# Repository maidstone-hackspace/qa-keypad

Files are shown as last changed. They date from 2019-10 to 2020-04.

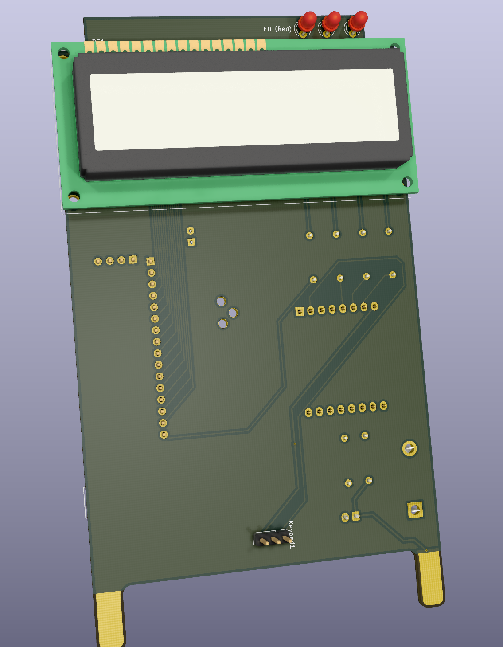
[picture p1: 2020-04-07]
PCB/Keypad_Front.png

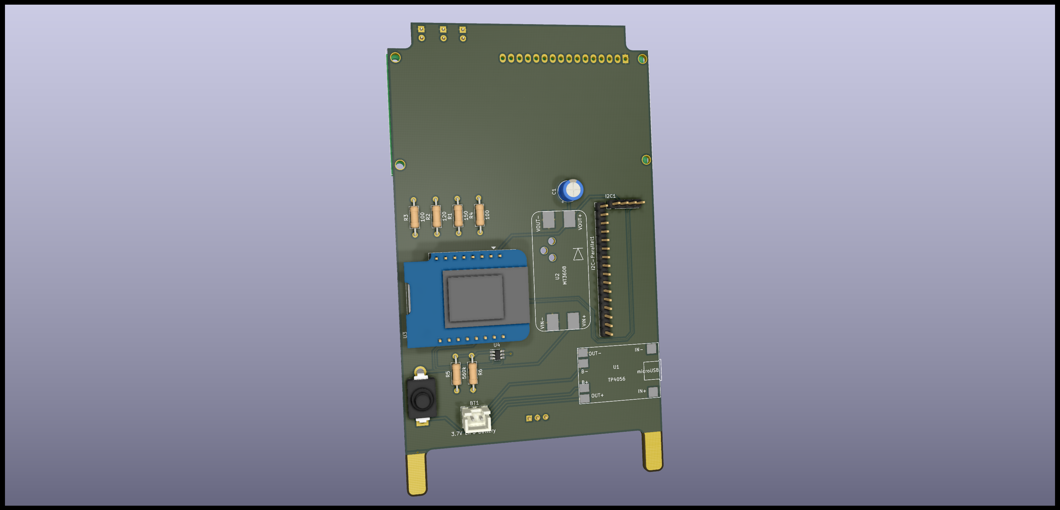
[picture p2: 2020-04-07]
PCB/Keypad_Rear.png

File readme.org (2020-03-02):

#+TITLE: Wemos QA keypad

* Device install

To setup a new device you can use the arduino software, you will need a plugin to upload the files in the =data= folder to your wemos device.

** Deploy requirements
https://github.com/esp8266/Arduino.git
https://github.com/esp8266/arduino-esp8266fs-plugin/releases/tag/0.4.0

** Build Requirements
You will also need various 3rd party libaries.
keypad.h 3.1.1 by Mark Stanley, Alexander Brevig https://wiring.uniandes.edu.co/source/trunk/wiring/

LiquidCrystal I2C by frank de Bradander https://github.com/johnrickman/LiquidCrystal_I2C

ESPAsyncWebServer https://github.com/me-no-dev/ESPAsyncWebServer/archive/master.zip

ESPAsyncTCP https://github.com/me-no-dev/ESPAsyncTCP

Extract and copy to arduino libries folder

* Device Setup

When switching on the device for the first time it will launch in access point mode to allow you to setup the device, connect to =weeeecfg= from a phone and enter password =weeeecfg= to setup the device. If the device can not connect to a local network it will relaunch the setup interface.

subsequent usage of the device will reuse the same settings as long as the device can connect.

The interfacing is using a simple web interface generated from this repository.

https://gitlab.com/olymk2/weecfg

#+RESULTS:
: None

* API example
** Keypad startup endpoint
#+BEGIN_SRC http :pretty :exports both
POST http://ng.snapwire-portal.co.uk/api/Startup
Content-Type: application/json

{"ControllerId": "DID1"}
#+END_SRC

#+RESULTS:
: {
:   "ControllerId": "DID1",
:   "AssignedName": "Bob"
: }

** Poll to determine when ready for next answer
#+BEGIN_SRC http :pretty :exports both
POST http://ng.snapwire-portal.co.uk/api/Poll
Content-Type: application/json

{}
#+END_SRC

#+RESULTS:
: {
:   "Timestamp": 132149528062145583,
:   "ReadyToAcceptAnswers": true
: }

** Example sending answer to api.
#+BEGIN_SRC http :pretty :exports both
POST http://ng.snapwire-portal.co.uk/api/SubmitAnswer
Content-Type: application/json

{"ControllerId": "sample string 1", "Answer": "A"}
#+END_SRC

#+RESULTS:
: {
:   "ConfirmReceived": true
: }

http://ng.snapwire-portal.co.uk/api/SubmitAnswer

* Later
** TODO gzip the html

The wemos is by no means fast so gzip so there is less data to send.
** TODO http error message on api failure.

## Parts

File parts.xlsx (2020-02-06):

WeMos D1 Mini | £1.58 | £31.65 | https://www.aliexpress.com/item/4000375278135.html
TP4056 | £0.24 | £4.77 | https://www.aliexpress.com/item/32802142444.html
MT3608 | £0.33 | £6.54 | https://www.aliexpress.com/item/4000207182126.html
18650 Li-ion cell (tabbed) | £0.00 |  | Paul?
16x2 LCD Character display | £1.43 | £28.67 | https://www.aliexpress.com/item/33007929472.html?spm=a2g0o.cart.0.0.64ca3c00Um8uOu&mp=1
I2C to Parallel Adaptor | £0.00 |  | included above
Mini Latching On/Off Switch | £0.00 |  | Paul?
MCP3421 (SOT23-6) | £1.03 | £20.67 | https://www.aliexpress.com/item/32881169619.html?spm=a2g0o.cart.0.0.61463c00gVNrOm&mp=1
1x16 Male pin header | £0.03 | £0.59 | https://www.aliexpress.com/item/32623553746.html
1x4 Male pin header | £0.00 |  | included above
1x3 Male pin header | £0.00 |  | included above
Analog output Keypad | £0.00 |  | Already purchased?
100 Ohm resistor | £0.02 | £0.40 | https://www.aliexpress.com/item/32952657927.html
500k Ohm resistor | £0.02 | £0.40
560k Ohm resistor | £0.02 | £0.40
PCB | £1.08 | £21.67 | https://jlcpcb.com

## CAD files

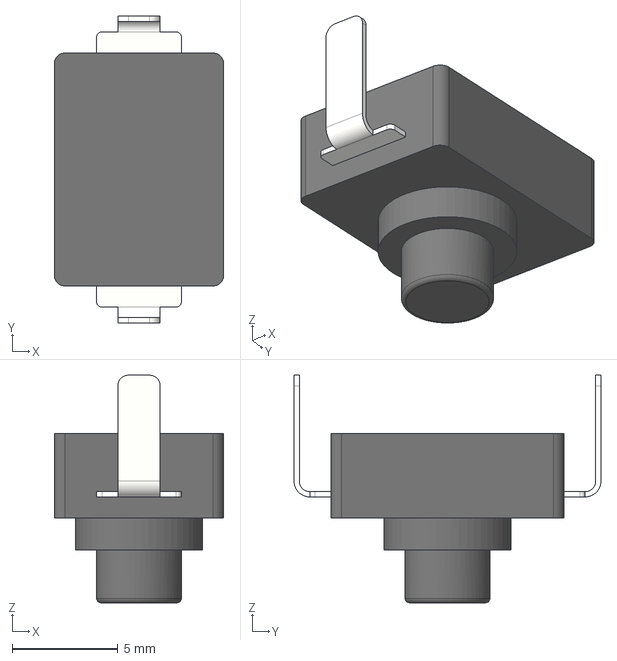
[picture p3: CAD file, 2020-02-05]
PCB/KiCad/Power Switch.step
8.00 x 14.5 x 10.8 mm

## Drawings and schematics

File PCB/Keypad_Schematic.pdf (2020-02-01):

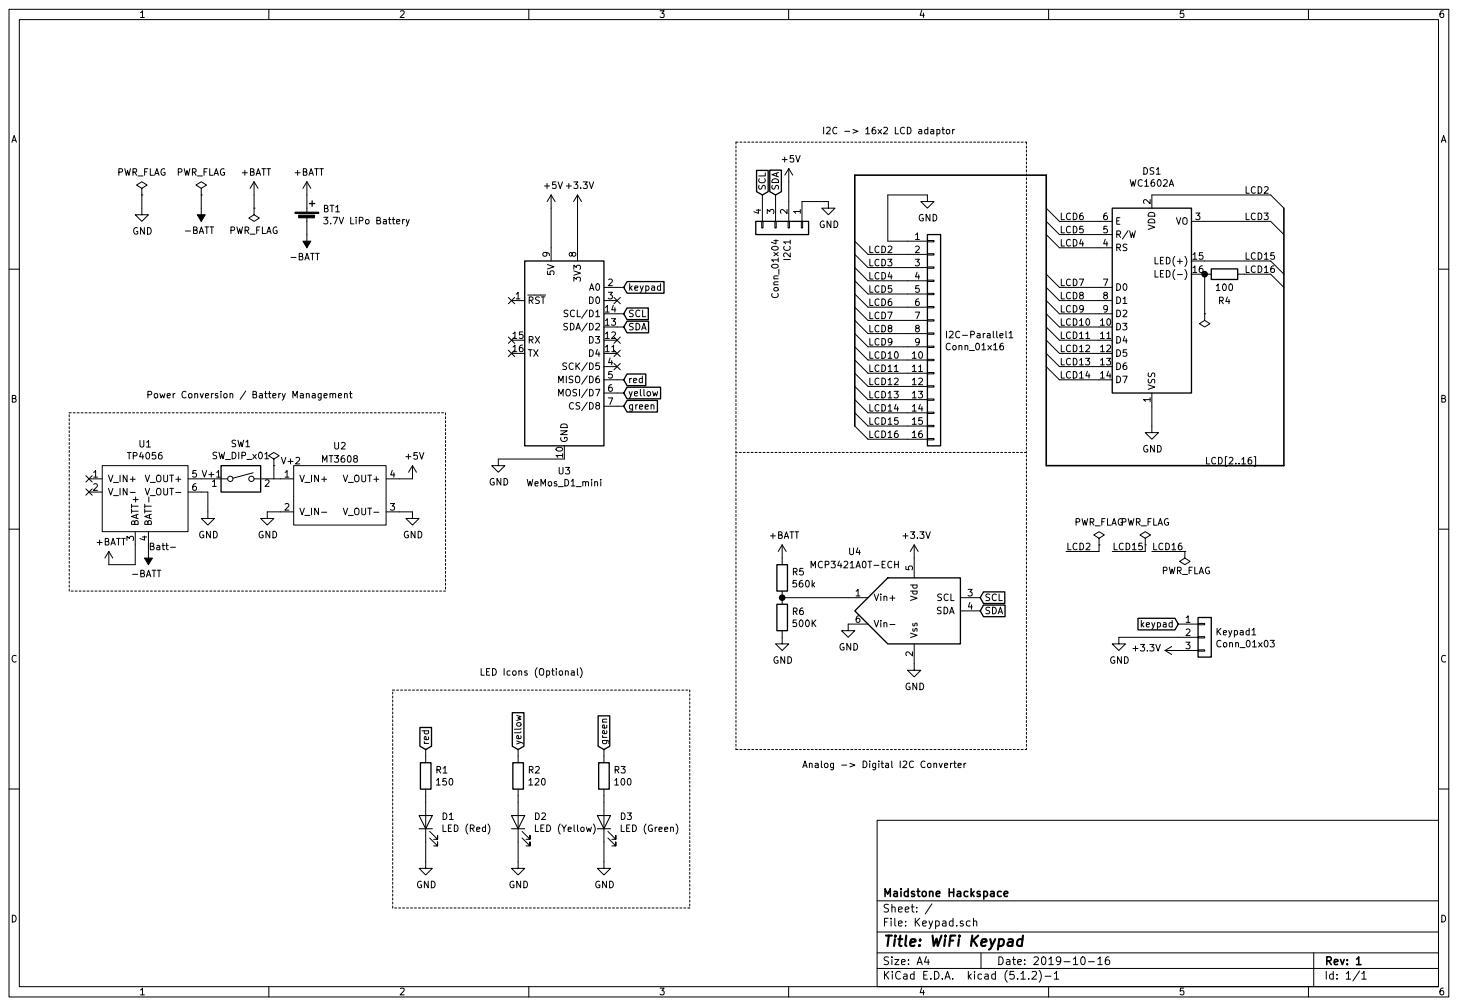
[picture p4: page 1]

File: Keypad.sch Sheet: / Maidstone Hackspace

Id: 1/1 Title: WiFi Keypad

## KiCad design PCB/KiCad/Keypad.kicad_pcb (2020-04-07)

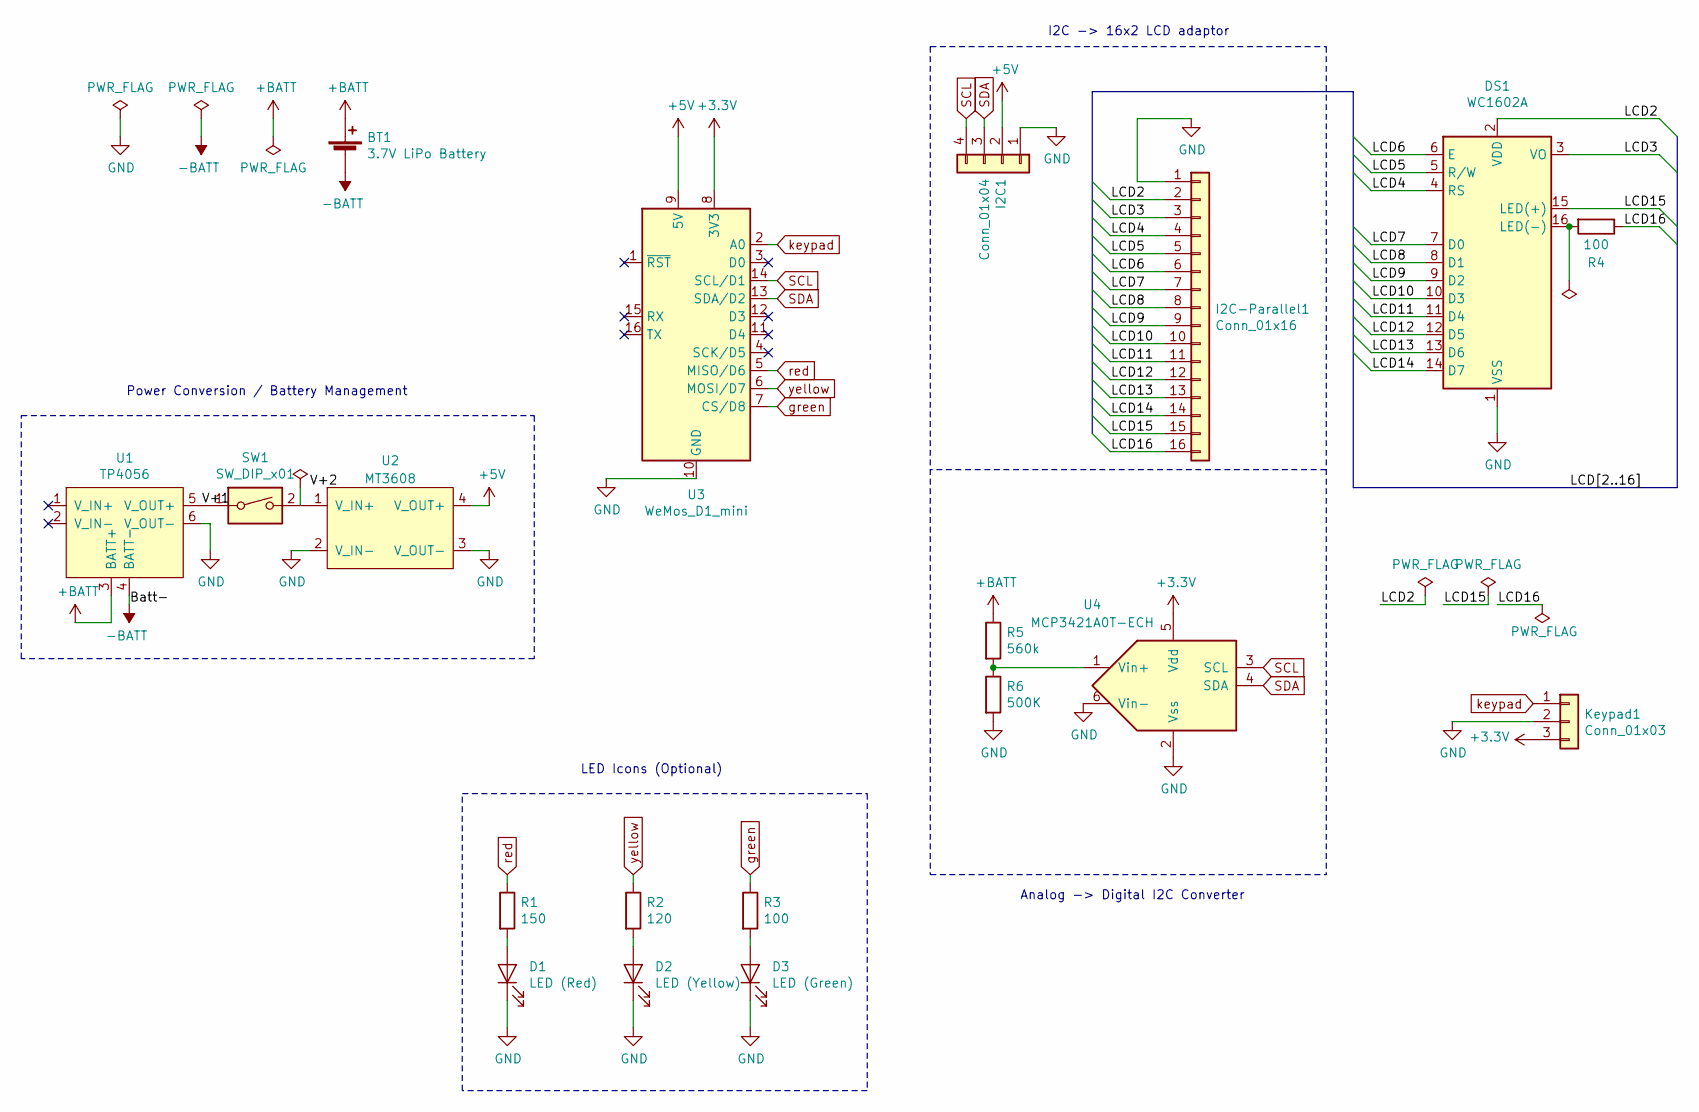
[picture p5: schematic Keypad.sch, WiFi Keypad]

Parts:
BT1: 3.7V LiPo Battery; JST_XH_B2B-XH-A_1x02_P2.50mm_Vertical
D1: LED (Red); LED_D3.0mm
D2: LED (Yellow); LED_D3.0mm
D3: LED (Green); LED_D3.0mm
DS1: WC1602A
I2C1: Conn_01x04; PinHeader_1x04_P2.54mm_Vertical
I2C-Parallel1: Conn_01x16; PinHeader_1x16_P2.54mm_Vertical
Keypad1: Conn_01x03; PinHeader_1x03_P2.54mm_Vertical
R1: 150; R_Axial_DIN0207_L6.3mm_D2.5mm_P10.16mm_Horizontal
R2: 120; R_Axial_DIN0207_L6.3mm_D2.5mm_P10.16mm_Horizontal
R3, R4: 100; R_Axial_DIN0207_L6.3mm_D2.5mm_P10.16mm_Horizontal
R5: 560k; R_Axial_DIN0207_L6.3mm_D2.5mm_P10.16mm_Horizontal
R6: 500K; R_Axial_DIN0207_L6.3mm_D2.5mm_P10.16mm_Horizontal
SW1: SW_DIP_x01; Mini_Latching_Torch_Switch
U1: TP4056; 4056E_LiIon_loader_SMT
U2: MT3608; MT3608_module_SMT
U3: WeMos_D1_mini; WEMOS_D1_mini_light
U4: MCP3421A0T-ECH; SOT-23-6_Handsoldering

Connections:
+3V3: Keypad1.3, U3.8 (3V3), U4.5 (Vdd)
+5V: I2C1.2, U2.4 (V_OUT+), U3.9 (5V); also elsewhere on the board
+BATT: BT1.1 (+), R5.1, U1.3 (BATT+)
-BATT: BT1.2 (-), U1.4 (BATT-)
/LCD2: DS1.2 (VDD), I2C-Parallel1.2
/LCD3: DS1.3 (VO), I2C-Parallel1.3
/LCD4: DS1.4 (RS), I2C-Parallel1.4
/LCD5: DS1.5 (R/W), I2C-Parallel1.5
/LCD6: DS1.6 (E), I2C-Parallel1.6
/LCD7: DS1.7 (D0), I2C-Parallel1.7
/LCD8: DS1.8 (D1), I2C-Parallel1.8
/LCD9: DS1.9 (D2), I2C-Parallel1.9
/LCD10: DS1.10 (D3), I2C-Parallel1.10
/LCD11: DS1.11 (D4), I2C-Parallel1.11
/LCD12: DS1.12 (D5), I2C-Parallel1.12
/LCD13: DS1.13 (D6), I2C-Parallel1.13
/LCD14: DS1.14 (D7), I2C-Parallel1.14
/LCD15: DS1.15 (LED(+)), I2C-Parallel1.15
/LCD16: I2C-Parallel1.16, R4.1
/V+1: SW1.1, U1.5 (V_OUT+)
GND: D1.1 (K), D2.1 (K), D3.1 (K), DS1.1 (VSS), I2C1.1, I2C-Parallel1.1, Keypad1.2, R6.2, U1.6 (V_OUT-), U2.2 (V_IN-), U2.3 (V_OUT-), U3.10 (GND), U4.2 (Vss), U4.6 (Vin-); also elsewhere on the board
unnamed: D1.2 (A), R1.2
unnamed: D2.2 (A), R2.2
unnamed: D3.2 (A), R3.2
unnamed: DS1.16 (LED(-)), R4.2
unnamed: R5.2, R6.1, U4.1 (Vin+)
unnamed: SW1.2, U2.1 (V_IN+)
SCL: I2C1.4, U3.14 (SCL/D1), U4.3 (SCL)
SDA: I2C1.3, U3.13 (SDA/D2), U4.4 (SDA)
green: R3.1, U3.7 (CS/D8)
keypad: Keypad1.1, U3.2 (A0)
red: R1.1, U3.5 (MISO/D6)
yellow: R2.1, U3.6 (MOSI/D7)

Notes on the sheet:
I2C -> 16x2 LCD adaptor
Analog -> Digital I2C Converter
LED Icons (Optional)
Power Conversion / Battery Management

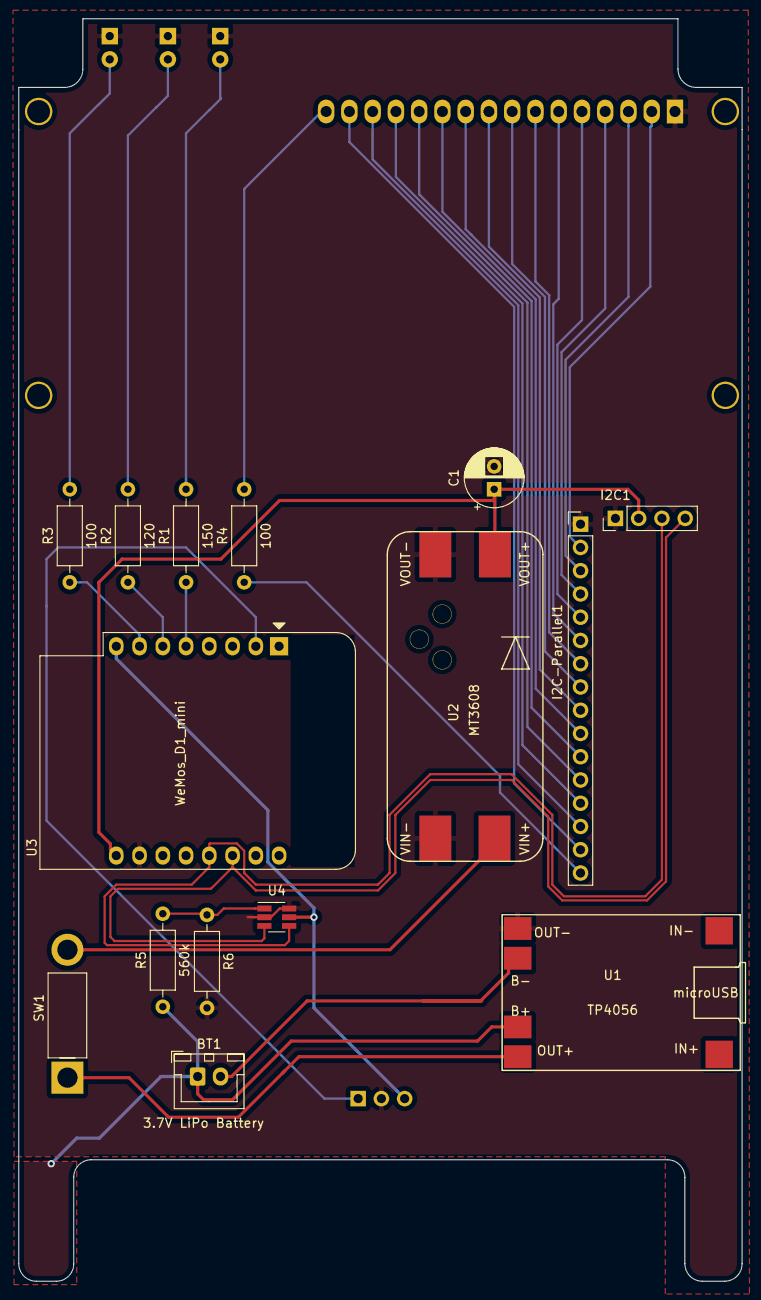
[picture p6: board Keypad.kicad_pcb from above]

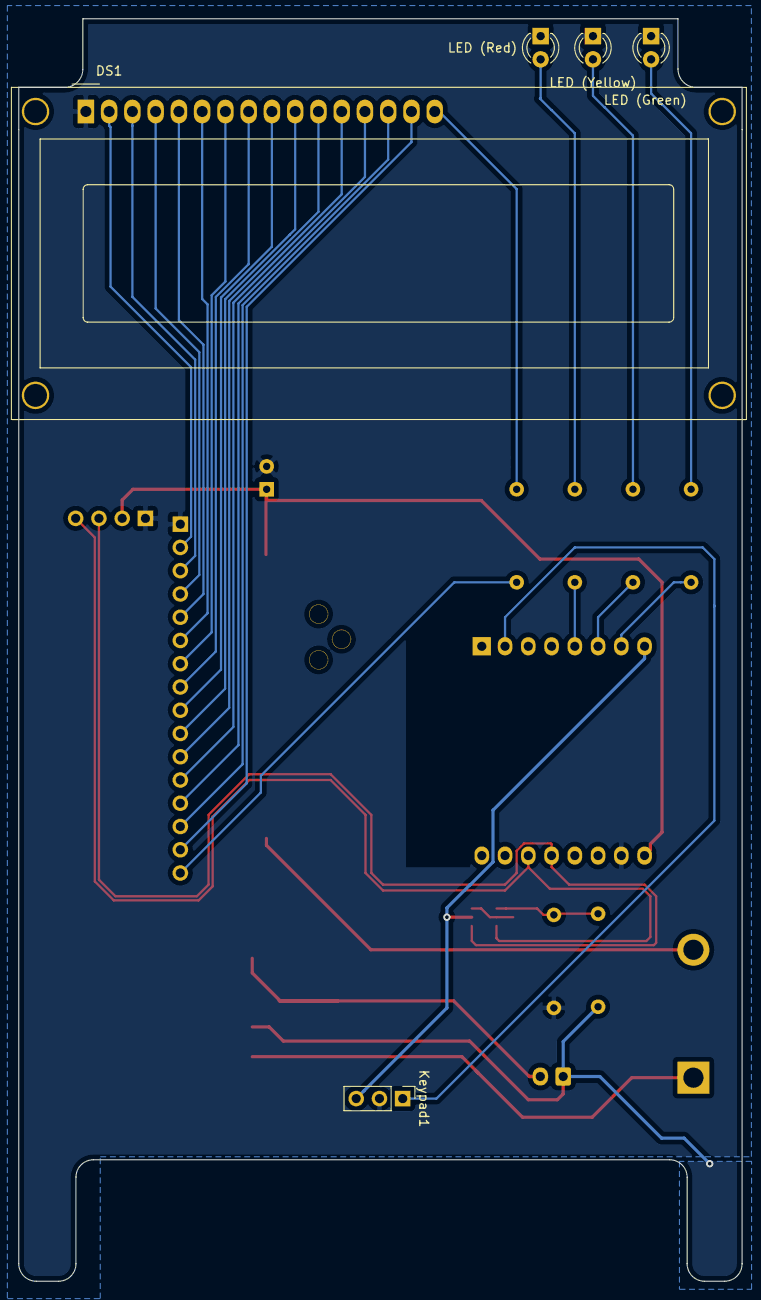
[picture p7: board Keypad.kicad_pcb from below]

Board: 2 copper layers, 79.0 x 137.9 mm, 20 parts (5 on the bottom side), 33 nets.

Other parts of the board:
C1: 100u; CP_Radial_D6.3mm_P2.50mm

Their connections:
+5V: C1.1; also elsewhere on the board
GND: C1.2; also elsewhere on the board

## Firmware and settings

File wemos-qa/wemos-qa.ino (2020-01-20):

#include <ArduinoJson.h>
#include <ESP8266WiFi.h>
#include <LiquidCrystal.h>
#include <stdio.h>
#include "qaapi.h"
#include "weecfg.h"
#include "weekeypad.h"
#include "weelcd.h"
#include "wemos-qa.h"

// array indexes of form field values
// these should match the order in form_fields
#define cfg_device_id 0
#define cfg_wifi_ssid 1
#define cfg_wifi_key 2
#define cfg_server 3

const char *form_fields[] = {"device-id", "wifi-ssid", "wifi-key", "server"};
int number_of_fields = 3; // total form fields minus 1 because zero based arrays
char config[3][50] = {};

bool qa_state_ready = false;
int qa_timestamp = 0;
char qa_key[1] = "";
char qa_last_key[1] = "";
// char users_name[12] = "";
char users_name[12] = "";
char controller_id[40] = "27f9035c-9e8c-4554-9af6-b1a6cbbc4e38";

char qa_lcd_top[16] = "";
char qa_lcd_bottom[16] = "";
char qa_counter_string[7];
int qa_counter = 0;
int qa_counter_start = 0;

bool setup_wifi(String hostname, char ssid[], char password[], int retrys) {
  Serial.print("Connecting to ");
  Serial.println(ssid);

  WiFi.mode(WIFI_STA);
  WiFi.persistent(false);
  WiFi.hostname(hostname);
  WiFi.begin(ssid, password);

  int retry_count = 0;
  // Might as well keep working if internet is unavailable
  while (WiFi.status() != WL_CONNECTED && retry_count < retrys) {
    delay(1000);
    Serial.print(".");
    retry_count += 1;
  }
  Serial.println("");

  if (WiFi.status() == WL_CONNECTED) {
    Serial.println("WiFi connected");
    Serial.print("IP address: ");
    Serial.println(WiFi.localIP());
    return true;
  }
  Serial.print("WiFi unable to connect with status of ");
  Serial.println(WiFi.status());
  WiFi.disconnect(true);
  delay(2000);
  return false;
}

void lcd_print(String msg) {
  lcd.clear();
  lcd.setCursor(0, 0);
  lcd.print(msg);
}

void lcd_print_bottom(String msg) {
  // lcd.clear();
  lcd.setCursor(0, 1);
  lcd.print(msg);
}

void redraw(String top, String bottom){
  lcd_print(top);
  lcd_print_bottom(bottom);
}

void setup() {
  Serial.begin(115200);
  lcdSetup();
  lcd_print("Starting...");
  delay(2000);

  // config_startup will return the mode it started in
  // either AP or normal mode
  if (config_startup("/config.txt", form_fields, config, number_of_fields) ==
      WEECFG_ACCESS_POINT_MODE) {
    lcd_print("Please setup.");
    return;
  }

  // config loaded
  if (setup_wifi("wemos", config[cfg_wifi_ssid], config[cfg_wifi_key], 20) ==
      false) {
    // wifi connection failed fall back to access point mode
    config_access_point(form_fields, number_of_fields);
    return;
  }
  lcd_print("Connected.");
  Serial.println(API_STARTUP);
  Serial.println(config[cfg_device_id]);
  //config[cfg_device_id]
  DynamicJsonDocument doc =
    send_payload(API_STARTUP, config[cfg_device_id], ' ', 0);
    //send_payload(API_STARTUP, "27f9035c-9e8c-4554-9af6-b1a6cbbc4e38", ' ', 0);
  //strcpy(controller_id, "27f9035c-9e8c-4554-9af6-b1a6cbbc4e38");
  strcpy(controller_id, (const char *)doc["ControllerId"]);
  strcpy(users_name, (const char *)doc["AssignedName"]);
  //redraw((String)users_name,(String)"hi");

}

/* void redraw(String top, String bottom){ */
/*   lcd_print(top); */
/*   lcd_print_bottom(bottom); */
/* } */

void loop() {
  qa_counter = millis() / 1000;
  //  lcd_print(qa_counter);

  // get char from keypad
  qa_key[0] = read_keypad_character();

  //reset everything
  if(qa_state_ready==0){
    qa_key[0]=NULL;
    qa_last_key[0]=NULL;
  }

  if (qa_counter_start != qa_counter) {
      Serial.println(API_POLL);

    DynamicJsonDocument doc =
         send_payload(API_POLL, config[cfg_device_id], ' ', 0);
    qa_state_ready = (bool)doc["ReadyToAcceptAnswers"];
    qa_timestamp = doc["Timestamp"]; 

    qa_counter_start = qa_counter;
    qa_timestamp += ONE_SECOND;

    //Serial.println(doc["ReadyToAcceptAnswers"]);
    Serial.println(qa_state_ready);

    if(qa_state_ready==1){
      if(qa_last_key[0]){
    Serial.println("--last key");
    Serial.println(qa_last_key);
        strcpy(qa_lcd_bottom, qa_last_key);
      }else{
        Serial.println("qa press answer");
        strcpy(qa_lcd_bottom, (const char *)"Press answer.");
      }
    }
    if(qa_state_ready==0){
      strcpy(qa_lcd_bottom, (const char *)"Locked waiting...");
    }

    Serial.println("++++++");
    Serial.println(qa_lcd_bottom);
    redraw((String)users_name,(String)qa_lcd_bottom);
  }

  // if a key is pressed work out what todo
  if (qa_key[0]) {
    if(qa_state_ready==1){
      strcpy(qa_last_key, qa_key);
      strcpy(qa_lcd_bottom, qa_last_key);
      redraw((String)users_name,(String)qa_lcd_bottom);
      Serial.println("Answer here ----");
      Serial.println(API_ANSWER);

      DynamicJsonDocument doc =
        send_payload(API_ANSWER, config[cfg_device_id], qa_key[0], qa_timestamp);
    }
  }


  /* if ((bool)qa_state_ready == false) { */
  /*   key = ' '; */
  /*   qa_key = ' '; */
  /* } */

  // if ((bool)qa_state_ready==true && key != qa_key && key!=' '){


    // strcpy(qa_key, (const char*)key);

    // DynamicJsonDocument doc =
    //    send_payload(API_ANSWER, config[cfg_device_id], qa_key, qa_timestamp);
    //} else {
    // lcd_print_bottom(String(qa_state_ready));

  // run time counter
  // lcd_print_bottom(itoa((millis() / 1000), qa_counter, 10));

  // work out time passed instead of delay
  // delay(ONE_SECOND); // one second

  delay(1);
}

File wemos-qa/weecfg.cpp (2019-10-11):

#include "ESPAsyncWebServer.h"
//#include <ESP8266WebServer.h>
#include "weecfg.h"
#include <ArduinoJson.h>
#include <DNSServer.h>
#include <ESP8266WiFi.h>
#include <FS.h>
//#include <WiFiClient.h>
#include <stdio.h>

bool weecfg_compressed = "";
bool weecfg_debug = true;
bool config_mode = WEECFG_NORMAL_MODE;
AsyncWebServer server(80);

void debug(const char msg[]) {
  if (weecfg_debug == false)
    return;
  Serial.println(msg);
}

void info(const char msg[]) { Serial.println(msg); }

bool loadConfig(String fileName, const char *form_fields[], char (*config)[50],
                int number_of_fields) {
  SPIFFS.begin();
  File dataFile = SPIFFS.open(fileName, "r");
  // no file so fail loadings
  if (!dataFile)
    return false;
  char *config_key;
  char *config_value;

  while (dataFile.available()) {
    // Lets read line by line from the file
    String line = dataFile.readStringUntil('\n');
    char char_array[line.length()];
    // convert to char array so wee can string compare
    line.toCharArray(char_array, line.length());
    config_key = strtok(char_array, "=");
    config_value = strtok(NULL, "=");

    // if strtok does not find a character it returns a null pointer
    // so handle it and skip the rest of this iteration
    if (config_key == NULL || config_value == NULL) {
      continue;
    }
    for (int i = 0; i < number_of_fields + 1; i++) {
      if (strcmp(form_fields[i], config_key) == 0) {
        strcpy(config[i], config_value);
      }
    }
  }
  info("+++ Loaded configuration from config.txt");
  for (int i = 0; i <= number_of_fields; i++) {
    debug(form_fields[i]);
    debug(config[i]);
  }
  return true;
}

bool handlePayload(AsyncWebServerRequest *request, const char *form_fields[],
                   int number_of_fields) {
  if (request->args() != number_of_fields)
    request->send(404, "text/plain", "Missing params.");

  File dataFile = SPIFFS.open("/config.txt", "w");
  for (int i = 0; i < number_of_fields + 1; i++) {
    int str_len = request->argName(i).length() + 1;
    char char_array[str_len];
    request->argName(i).toCharArray(char_array, str_len);
    for (int f = 0; f < number_of_fields + 1; f++) {
      if (strcmp(form_fields[f], char_array) == 0) {
        dataFile.print(request->argName(i));
        dataFile.print("=");
        dataFile.println(request->arg(i));
      }
    }
  }

  dataFile.close();
  request->send(200, "text/plain", "success");
  info("Config saved restarting with new settings.");
  WiFi.softAPdisconnect(true);
  WiFi.disconnect(true);
  delay(2000);
  ESP.restart();
  return true;
}

int config_access_point(const char *form_fields[], int number_of_fields) {
  info("Access point launched, please connect to weeeecfg and configure "
       "device.");
  WiFi.disconnect();
  WiFi.hostname("WEECFGAP");
  WiFi.persistent(false);
  WiFi.mode(WIFI_AP);

  if (WiFi.softAP("weeeecfg", "weeeecfg") == false) // Start the access point
    debug("Failed to launch access point, values to short must be 8 chars or "
          "greater.");
  info("Config page available on IP address:\t");
  info(WiFi.softAPIP().toString().c_str());

  // access point configured to setup required routes
  server.rewrite("/", "/index.html");
  server.serveStatic("/index.html", SPIFFS, "/index.html" WEECFG_COMPRESSED);
  server.serveStatic("/tachyon.css", SPIFFS, "/tachyon.css" WEECFG_COMPRESSED);
  server.serveStatic("/all.min.css", SPIFFS, "/all.min.css" WEECFG_COMPRESSED);
  server.serveStatic("/form.edn", SPIFFS, "/form.edn" WEECFG_COMPRESSED);
  server.serveStatic("/main.js", SPIFFS, "/main.js" WEECFG_COMPRESSED);
  server.serveStatic("/dev-main.js", SPIFFS, "/dev-main.js" WEECFG_COMPRESSED);
  server.serveStatic("/faavicon.ico", SPIFFS, "/favicon.ico" WEECFG_COMPRESSED);
  server.serveStatic("/webfonts/fa-solid-900.woff2", SPIFFS,
                     "/fa-solid-900.woff2" WEECFG_COMPRESSED);
  // only serve the config file in debug mode
  if (weecfg_debug == true)
    server.serveStatic("/config.txt", SPIFFS, "/config.txt");

  // Route to actually store the config file.
  server.on("/save", HTTP_GET,
            [form_fields, number_of_fields](AsyncWebServerRequest *request) {
              handlePayload(request, form_fields, number_of_fields);
            });

  server.begin();
  config_mode = WEECFG_ACCESS_POINT_MODE;
  return config_mode;
}

int config_startup(String fileName, const char *fields[], char (*config)[50],
                   int number_of_fields) {
  SPIFFS.begin();
  if (loadConfig(fileName, fields, config, number_of_fields) == true) {
    info("Configuration file detected and loaded.");
    return config_mode;
  }
  config_mode = WEECFG_ACCESS_POINT_MODE;
  config_access_point(fields, number_of_fields);
  return config_mode;
}

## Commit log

2019-09-19 Initial code to setup the device on a local network.
2019-10-07 Basic lcd code, and sample json request code.
2019-10-14 Current code, now displays user name on screen.
2019-10-17 Added rev 1 PCB files
    [Keypad-B_Cu.gbr, Keypad-B_Mask.gbr, Keypad-B_SilkS.gbr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]
2020-01-15 Add code for new keypad, code maps to chars small bug needs fixing with linking.
    [wemos.ino]
2020-01-20 Fix linking issue, and rename from wemos to avoid conflicts.
    [qaapi.cpp, weecfg.cpp]
2020-02-01 Analog Keypad
    Revision to use analog output keypad.
    [Keypad-B_Cu.gbr, Keypad-B_Mask.gbr, Keypad-B_SilkS.gbr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]
2020-02-05 kicad files updated.
    [Keypad.kicad_pcb, Keypad.sch, Power Switch.step]
2020-02-06 parts list
    [parts.xlsx]
2020-04-07 adjustments
    LCD moved 2mm in. Wemos rotated 180. 100uF cap added.
    [Keypad-B_Cu.gbr, Keypad-B_Mask.gbr, Keypad-B_SilkS.gbr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]
